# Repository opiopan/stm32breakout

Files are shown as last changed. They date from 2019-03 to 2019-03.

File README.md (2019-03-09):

Breakout Board for STM32
===
board image

This hardware design is published under open source lincence. You can use and modify this design freely. There is also no limitation in commercial use.

This breakout board is designed to install any QFP32 formfactor STM32 chip, and following functions are installed.

- +3.3V power supplay translated from micro USB +5V input
- 16MHz crystal to genarate accurate clock which enable to drive USB
- two buttons to reset and to specify boot mode
- 4 pin connector for debugger (SWCLK, SWDIO, NRST, and GND)
- USB data signal pins (PA11, PA12) are exported via micro USB connector, that means you can use DFU to download firmware

Please note that USB data communication function doesn't work if a STM32 MCU which has no USB functionality such as [STM32F303K8](https://www.st.com/content/st_com/en/products/microcontrollers-microprocessors/stm32-32-bit-arm-cortex-mcus/stm32-mainstream-mcus/stm32f3-series/stm32f303/stm32f303k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).<br>
[STM32F042K6](https://www.st.com/content/st_com/en/products/microcontrollers-microprocessors/stm32-32-bit-arm-cortex-mcus/stm32-mainstream-mcus/stm32f0-series/stm32f0x2/stm32f042k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) is a good candidate to use all function of this breakout board.

## PCB Design
Eagle PCB design files are placed at [here](./pcb/).
<p align="center">
PCB schema
</p>
<p align="center">
PCB image
</p>

## BOM list

Components | Value / Product Number | Remarks
-----------|------------------------|------------------------------
U1         | STM32 (QFP32)          |
U2         | MCP1703AT-3302E/CB     | SOT-23A 3.3V LDO
J1         | ZX62-B-5PA(33)         | Hirose Micro USB female connector
X1         | 16MHz Crystal (3225)   | load capacitance: 10pF
C1, C2, C9 | 1uF (1005)             |
C3, C4, C10| 0.1uF (1005)           |
C5         | 4.7uF (1005)           |
C6, C7     | 15pF (1005)            | need to change value if X1's load capacitance is not 10pF
C8         | 10nF (1005)
R1         | 10k ohm (1005)         |

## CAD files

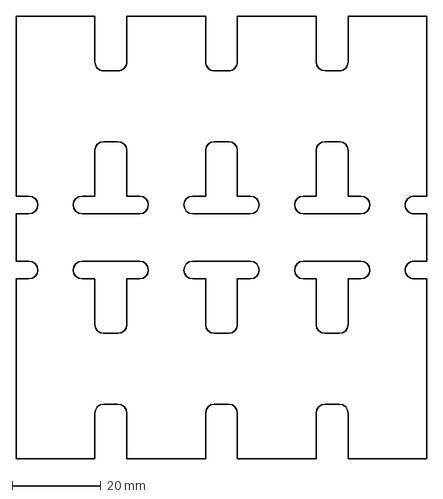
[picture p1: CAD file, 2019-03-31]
panelize/outline.dxf
92.8 x 100.0 mm

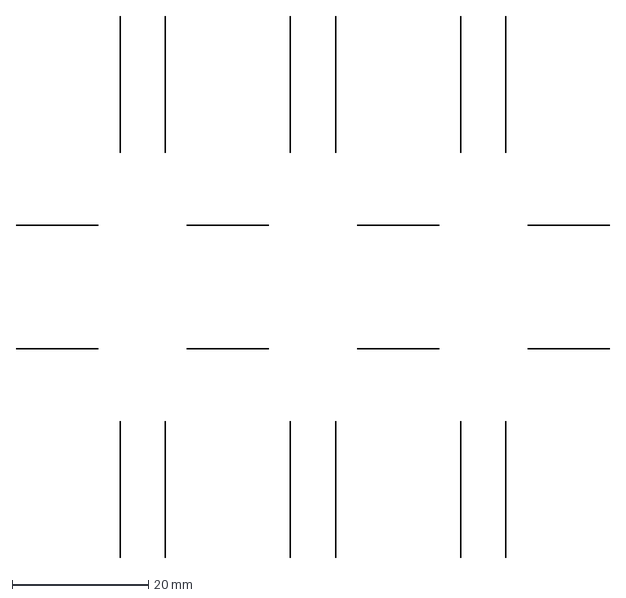
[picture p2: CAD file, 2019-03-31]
panelize/mousebites.dxf
87.0 x 79.4 mm

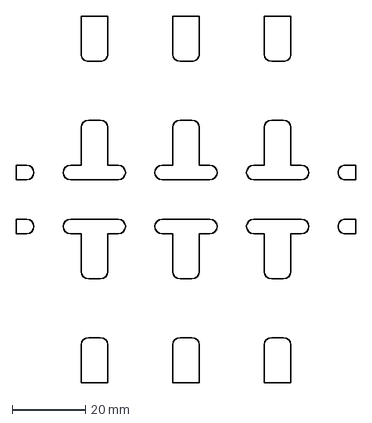
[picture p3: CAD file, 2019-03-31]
panelize/fill.dxf
92.8 x 100.0 mm

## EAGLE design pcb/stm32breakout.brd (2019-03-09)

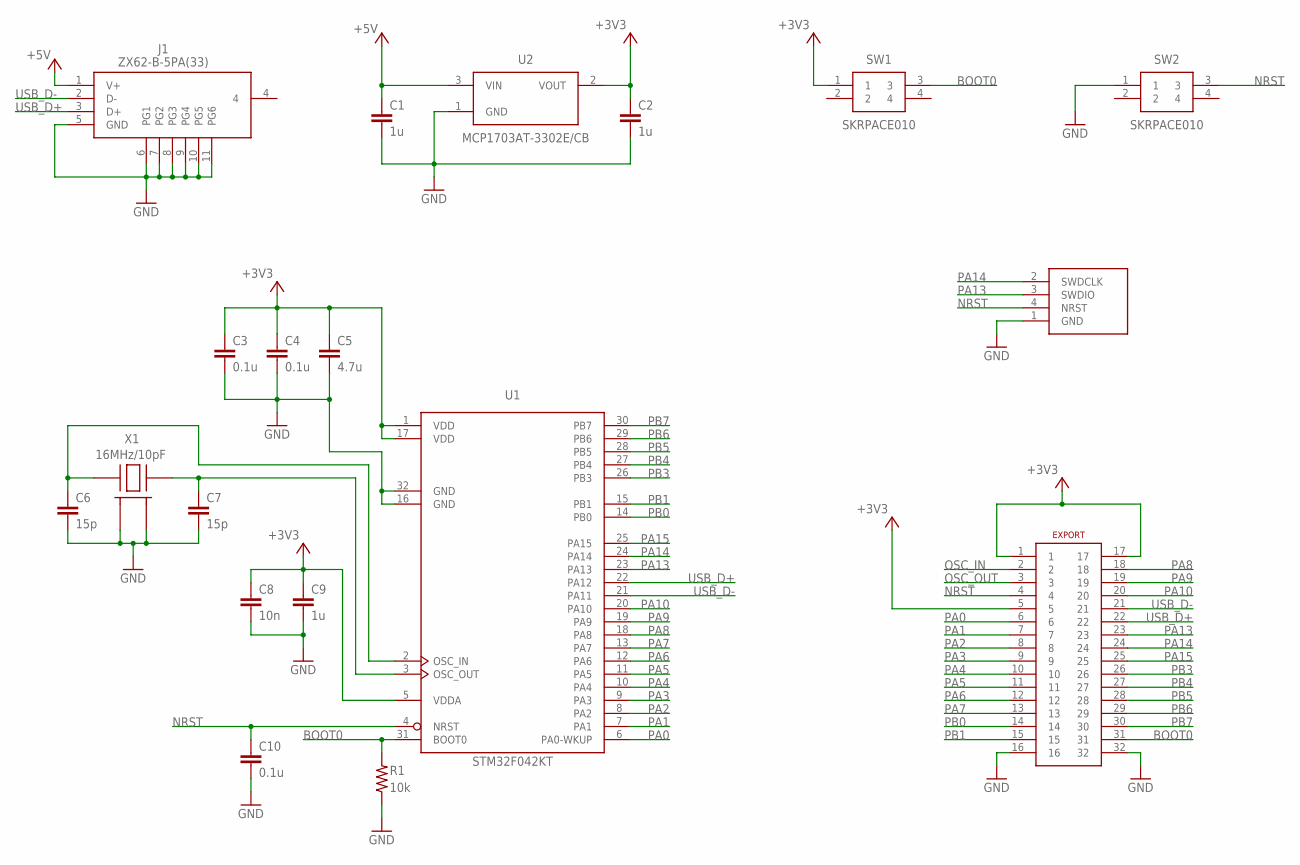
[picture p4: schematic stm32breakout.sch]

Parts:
C1, C2, C9: 1u; RCL_C0402_HS
C3, C4, C10: 0.1u; RCL_C0402_HS
C5: 4.7u; RCL_C0402_HS
C6, C7: 15p; RCL_C0402_HS
C8: 10n; RCL_C0402_HS
EXPORT: 2X16PIN
J1: ZX62-B-5PA(33); ZX62-B-5PA(33)-TRUE-HANDSOLD
R1: 10k; RCL_R0402_HS
SW1, SW2: SKRPACE010; SMT(4.2X3.2)
U1: STM32F042KT; LQFP32-M
U2: MCP1703AT-3302E/CB; SOT23
U$1: 4PIN-DEBUG
X1: 16MHz/10pF; CRYSTAL3225-HS

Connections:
+3V3: C2.1, C3.1, C4.1, C5.1, C8.1, C9.1, EXPORT.1, EXPORT.5, EXPORT.17, SW1.1, U1.1 (VDD), U1.5 (VDDA), U1.17 (VDD), U2.2 (VOUT)
+5V: C1.1, J1.1 (V+), U2.3 (VIN)
BOOT0: EXPORT.31, R1.2, SW1.3, U1.31 (BOOT0)
GND: C1.2, C2.2, C3.2, C4.2, C5.2, C6.2, C7.2, C8.2, C9.2, C10.2, EXPORT.16, EXPORT.32, J1.5 (GND), J1.6 (PG1), J1.7 (PG2), J1.8 (PG3), J1.9 (PG4), J1.10 (PG5), J1.11 (PG6), R1.1, SW2.1, U1.16 (GND), U1.32 (GND), U2.1 (GND), U$1.1 (GND), X1.2 (GND_1), X1.4 (GND_2)
NRST: C10.1, EXPORT.4, SW2.3, U1.4 (NRST), U$1.4 (NRST)
OSC_IN: C6.1, EXPORT.2, U1.2 (OSC_IN), X1.1 (HOT_1)
OSC_OUT: C7.1, EXPORT.3, U1.3 (OSC_OUT), X1.3 (HOT_2)
PA0: EXPORT.6, U1.6 (PA0-WKUP)
PA1: EXPORT.7, U1.7 (PA1)
PA2: EXPORT.8, U1.8 (PA2)
PA3: EXPORT.9, U1.9 (PA3)
PA4: EXPORT.10, U1.10 (PA4)
PA5: EXPORT.11, U1.11 (PA5)
PA6: EXPORT.12, U1.12 (PA6)
PA7: EXPORT.13, U1.13 (PA7)
PA8: EXPORT.18, U1.18 (PA8)
PA9: EXPORT.19, U1.19 (PA9)
PA10: EXPORT.20, U1.20 (PA10)
PA13: EXPORT.23, U1.23 (PA13), U$1.3 (SWDIO)
PA14: EXPORT.24, U1.24 (PA14), U$1.2 (SWDCLK)
PA15: EXPORT.25, U1.25 (PA15)
PB0: EXPORT.14, U1.14 (PB0)
PB1: EXPORT.15, U1.15 (PB1)
PB3: EXPORT.26, U1.26 (PB3)
PB4: EXPORT.27, U1.27 (PB4)
PB5: EXPORT.28, U1.28 (PB5)
PB6: EXPORT.29, U1.29 (PB6)
PB7: EXPORT.30, U1.30 (PB7)
USB_D+: EXPORT.22, J1.3 (D+), U1.22 (PA12)
USB_D-: EXPORT.21, J1.2 (D-), U1.21 (PA11)

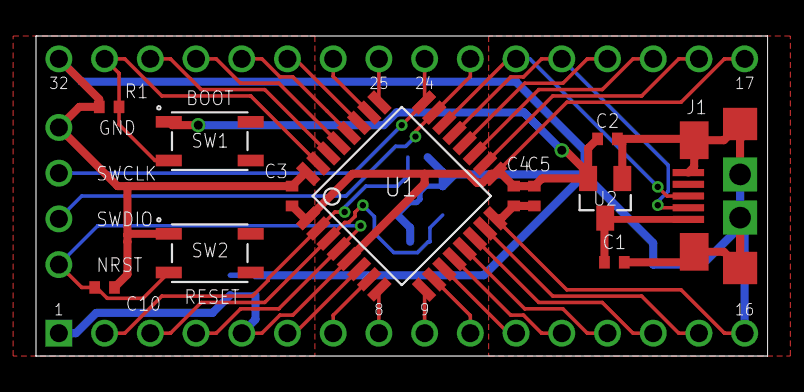
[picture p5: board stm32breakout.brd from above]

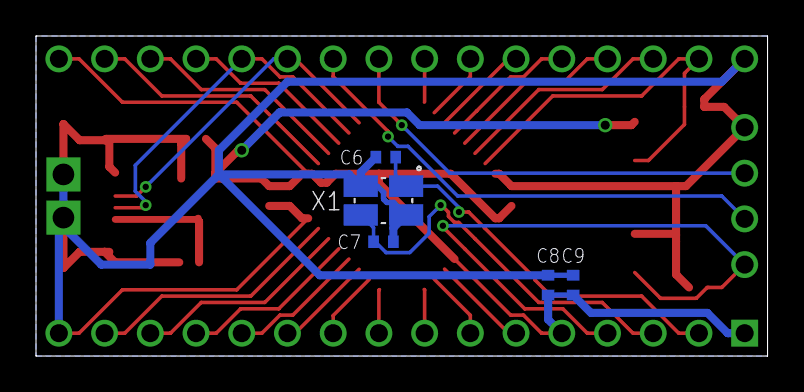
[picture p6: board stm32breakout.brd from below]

Board: 2 copper layers, 40.6 x 17.8 mm, 19 parts (5 on the bottom side), 30 nets.
